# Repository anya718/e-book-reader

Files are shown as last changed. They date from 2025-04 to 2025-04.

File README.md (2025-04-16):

Biro Anya-Andreea 332CA

# OpenBook

## Diagrama bloc
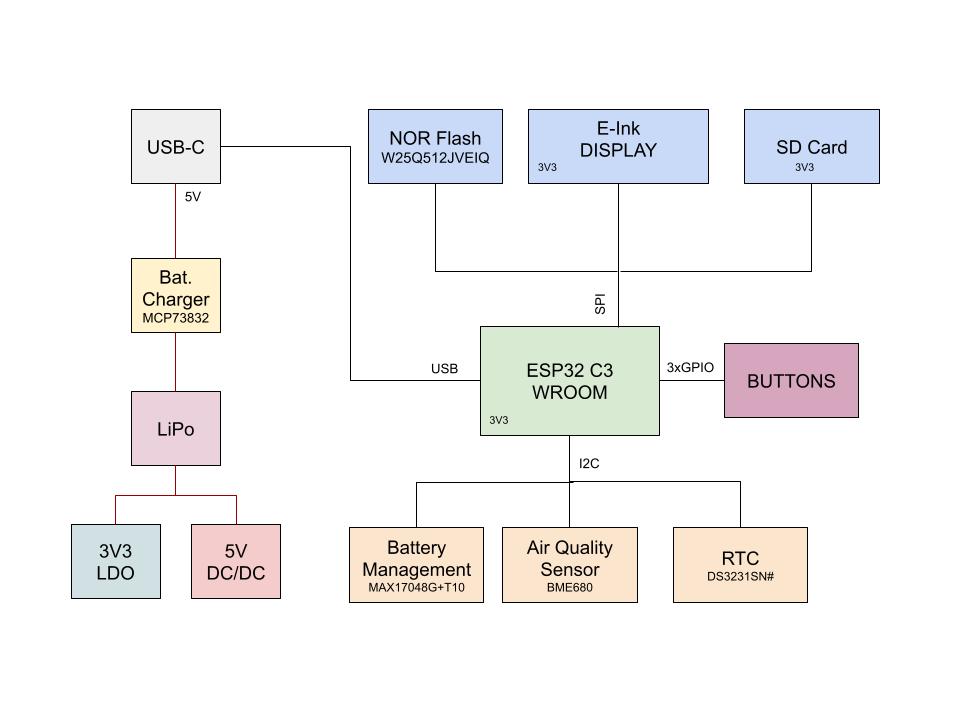
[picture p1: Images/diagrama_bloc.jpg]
Diagrama bloc


## BOM
| Componenta | Descriere | Sursa | Datasheet |
|---|---|---|---|
| ESP32-C6-WROOM-1-N8 | Multiprotocol Module ESP32 |[Mouser](https://ro.mouser.com/ProductDetail/Espressif-Systems/ESP32-C6-WROOM-1-N8?qs=8Wlm6%252BaMh8ST02Gmwp74cw%3D%3D)|[Datasheet](https://ro.mouser.com/datasheet/2/891/Espressif_ESP32_C6_WROOM_1__Datasheet_V0_1_PRELIMI-3239987.pdf)|
| USB4110-GF-A | USB Type C Connector |[Mouser](https://ro.mouser.com/ProductDetail/GCT/USB4110-GF-A?qs=KUoIvG%2F9IlYiZvIXQjyJeA%3D%3D)|[Datasheet](https://ro.mouser.com/datasheet/2/837/GCT_USB4110_Product_Drawing___20k_cycles-3455479.pdf)|
| 112A-TAAR-R03 | Micro SD Card Socket |[Comet](https://store.comet.srl.ro/Catalogue/Product/43497/)|[Datasheet](https://store.comet.bg/download-file.php?id=27596)|
| BME680 | Air Quality Sensor |[Mouser](https://ro.mouser.com/ProductDetail/Bosch-Sensortec/BME680?qs=v271MhAjFHjo0yA%2FC4OnDQ%3D%3D)|[Datasheet](https://ro.mouser.com/datasheet/2/783/BST_BME680_DS001-1509608.pdf)|
| DS3231SN# | Real Time Clock |[Mouser](https://ro.mouser.com/ProductDetail/700-DS3231SN%23)|[Datasheet](https://ro.mouser.com/datasheet/2/609/DS3231-3421123.pdf)|
| EVQ-P4MB3K | Tactile Switch |[Mouser](https://ro.mouser.com/ProductDetail/Panasonic/EVQ-P4MB3K?qs=0aNVN3t2tDvlcmyoDZjvlA%3D%3D)|[Datasheet](https://4donline.ihs.com/images/VipMasterIC/IC/PANA/PANA-S-A0000771493/PANA-S-A0000771493-1.pdf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)|
| MCP73831-2ACI/MC | Battery Charge Controller |[Mouser](https://ro.mouser.com/ProductDetail/579-MCP73831-2ACI-MC)|[Datasheet](https://ro.mouser.com/datasheet/2/268/MCP73831_Family_Data_Sheet_DS20001984H-3441711.pdf)|
| MAX17048G+T10 | Battery Management |[Mouser](https://ro.mouser.com/ProductDetail/Analog-Devices-Maxim-Integrated/MAX17048G%2bT10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)|[Datasheet](https://ro.mouser.com/datasheet/2/609/MAX17048_MAX17049-3469099.pdf)|
| FH34SRJ-24S-0.5SH(99) | EPD Connector |[Mouser](https://ro.mouser.com/ProductDetail/Hirose-Connector/FH34SRJ-24S-0.5SH99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)|[Datasheet](https://ro.mouser.com/datasheet/2/185/FH34SRJ_24S_0_5SH_99__CL0580_1255_6_99_2DDrawing_0-1615044.pdf)|
| PRT-14417 | Qwiic JST Connector |[Mouser](https://ro.mouser.com/ProductDetail/SparkFun/PRT-14417?qs=wd5RIQLrsJhgdz%2FpmZ%2F3GQ%3D%3D)|[Datasheet](https://ro.mouser.com/datasheet/2/813/Qwiic_Connector_Datasheet-1223982.pdf)|
| W25Q512JVEIQ | NOR Flash |[Mouser](https://ro.mouser.com/ProductDetail/Winbond/W25Q512JVEIQ?qs=l7cgNqFNU1jw6svr3at6tA%3D%3D)|[Datasheet](https://ro.mouser.com/datasheet/2/949/Winbond_W25Q512JV_Datasheet-3240039.pdf)|
| R0402 | Resistor |[Mouser](https://ro.mouser.com/ProductDetail/Panasonic/ERJ-2BWJR051X?qs=pojneS%2F1sjx%252Bdeocf%252BMSog%3D%3D)|[Datasheet](https://industrial.panasonic.com/cdbs/www-data/pdf/RDN0000/AOA0000C313.pdf)|
| B72540T0300K062 | Varistor |[Mouser](https://ro.mouser.com/ProductDetail/EPCOS-TDK/B72540T0300K062?qs=dEfas%2FXlABK4d0Dv0OnYYg%3D%3D)|[Datasheet](https://www.tdk-electronics.tdk.com/inf/75/db/CTVS_14/Surge_protection_series.pdf)|
| C0402C475K8PACTU | Capacitor |[Mouser](https://ro.mouser.com/ProductDetail/KEMET/C0402C475K8PACTU?qs=ulEaXIWI0c9ebKRT3r3htg%3D%3D)|[Datasheet](https://ro.mouser.com/datasheet/2/447/KEM_C1006_X5R_SMD-3316465.pdf)|
| T491B107M006AT | Tantalum Capacitor |[Mouser](https://ro.mouser.com/ProductDetail/KEMET/T491B107M006AT?qs=U312oeP%2FpiHOgyk6KO2m0g%3D%3D)|[Datasheet](https://ro.mouser.com/datasheet/2/447/KEM_T2005_T491-3316937.pdf)|
| USBLC6-2SC6Y | ESD Protection Diode |[Mouser](https://ro.mouser.com/ProductDetail/STMicroelectronics/USBLC6-2SC6Y?qs=gNDSiZmRJS%2FOgDexvXkdow%3D%3D)|[Datasheet](https://ro.mouser.com/datasheet/2/389/usblc6_2sc6y-1852505.pdf)|
| PGB1010603MR | ESD Protection Diode |[Mouser](https://ro.mouser.com/ProductDetail/Littelfuse/PGB1010603MR?qs=gu7KAQ731URLg4GSnNNN7Q%3D%3D)|[Datasheet](https://www.littelfuse.com/assetdocs/pulseguard-esd-suppressors-pgb1-datasheet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)|
| SD0805S020S1R0 | Schottky Diode |[Mouser](https://ro.mouser.com/ProductDetail/KYOCERA-AVX/SD0805S020S1R0?qs=jCA%252BPfw4LHbpkAoSnwrdjw%3D%3D)|[Datasheet](https://ro.mouser.com/datasheet/2/40/schottky-3165252.pdf)|
| MBR0530-TP | Small Signal Schottky Diode |[Mouser](https://ro.mouser.com/ProductDetail/Micro-Commercial-Components-MCC/MBR0530-TP?qs=KFo7JewZbUECRHkxGanrdg%3D%3D)|[Datasheet](https://ro.mouser.com/datasheet/2/258/MBR0520_MBR0580_SOD123_-2492194.pdf)|
| LSM0603472V | Single Color LED |[Mouser](https://ro.mouser.com/ProductDetail/VCC/LSM0603472V?qs=%252BEew9%252B0nqrBygsW37Z2ISQ%3D%3D)|[Datasheet](https://ro.mouser.com/datasheet/2/423/LSM0603472V_(1)-1379786.pdf)|
| DMG2305UX-7 | MOSFET P-Ch |[Mouser](https://ro.mouser.com/ProductDetail/Diodes-Incorporated/DMG2305UX-7?qs=L1DZKBg7t5F%2FNBHrjfxC%252Bg%3D%3D)|[Datasheet](https://www.diodes.com/assets/Datasheets/DMG2305UX.pdf)|
| SI1308EDL-T1-GE3 | MOSFET N-Ch |[Mouser](https://ro.mouser.com/ProductDetail/Vishay-Semiconductors/SI1308EDL-T1-GE3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)|[Datasheet](https://www.vishay.com/docs/63399/si1308edl.pdf)|
| CPH3225A | Supercapacitor |[Mouser](https://ro.mouser.com/ProductDetail/Seiko-Semiconductors/CPH3225A?qs=3etwrb1wR%252BhUOph6lAO7eg%3D%3D)|[Datasheet](https://ro.mouser.com/datasheet/2/360/Seiko_Instruments_MicroBattery_E_20230330_2024Jan_-3561061.pdf)|
| 744043680 | SMD Inductor |[Mouser](https://ro.mouser.com/ProductDetail/Wurth-Elektronik/744043680?qs=PGXP4M47uW6VkZq%252BkzjrHA%3D%3D)|[Datasheet](https://www.we-online.com/components/products/datasheet/744043680.pdf)|
| BD5229G-TR | Voltage Detector |[Mouser](https://ro.mouser.com/ProductDetail/ROHM-Semiconductor/BD5229G-TR?qs=4kLU8WoGk0vvnhrrYwdszw%3D%3D)|[Datasheet](https://fscdn.rohm.com/en/products/databook/datasheet/ic/power/voltage_detector/bd52xxg-e.pdf)|
| XC6220A331MR-G | LDO Voltage Regulator |[Mouser](https://ro.mouser.com/ProductDetail/Torex-Semiconductor/XC6220A331MR-G?qs=AsjdqWjXhJ8ZSWznL1J0gg%3D%3D)|[Datasheet](https://ro.mouser.com/datasheet/2/760/xc6220-3371556.pdf)|

## Descriere funcționalitate hardware
Proiectul **OpenBook** are ca scop dezvoltarea unui dispozitiv portabil de afișare a informațiilor, cu consum redus de energie, conectivitate Wi-Fi și senzori de mediu.

### Module și interfețe utilizate

- **ESP32-C6** – Microcontroller central cu suport pentru Wi-Fi și BLE. Rulează logica principală și gestionează comunicația cu toate perifericele.
- **BME680** – Senzor pentru calitatea aerului, conectat prin magistrala I2C.
- **DS3231SN** – Ceas de timp real (RTC), conectat I2C.
- **W25Q512JVEIQ** – Memorie NOR Flash SPI pentru stocare de date suplimentară.
- **MAX17048** – Circuit de monitorizare a bateriei, interfață I2C.
- **MCP73831** – Controler de încărcare baterie LiPo.
- **Conector EPD + ecran E-Ink** – Conectat SPI, pentru afișare cu consum redus.
- **Slot microSD** – SPI, pentru citire/scriere fișiere.
- **Buton tactile (EVQ-P4MB3K)** – Intrare digitală, GPIO.
- **Conector USB-C (USB4110-GF-A)** – Încărcare și interfață serială.
- **LED + rezistor + MOSFET** – Indicatoare vizuale, controlate de GPIO.
- **Diodă Schottky, varistori, ESD diode** – Protecție electrică.

### Comunicație și consum

- I2C: folosit pentru BME680, RTC, Battery Gauge
- SPI: utilizat pentru ecranul E-Ink, memoria Flash și SD card
- GPIO: pentru butoane, LED-uri, MOSFET-uri
- UART: pentru debugging via USB
- Estimare consum: 
    - **Mod Activ:** ~220 mA @ 3.3V → ~727 mW  
    - **Mod Sleep:** ~27 µA @ 3.3V → ~0.089 mW  
    - **Autonomie estimată:** ~14 zile cu baterie Li-Po 1200mAh

## Mapare Pini ESP32-C6

| Componentă | Pin ESP32-C6 | Interfață |
|---|---|---|
| BME680 | GPIO4 (SDA), GPIO5 (SCL) | I2C |
| DS3231SN | GPIO4, GPIO5 | I2C |
| E-Ink Display | GPIO10, GPIO11, ...  | SPI |
| SD Card | GPIO10, GPIO11, ...  | SPI |
| MAX17048 | GPIO4, GPIO5 | I2C |
| MCP73831 | GPIO22 (STAT) | GPIO |
| Buton | GPIO12 | GPIO |
| LED | GPIO13 | GPIO |
| UART (debug) | GPIO20 (TX), GPIO21 (RX) | UART |

## Alte Informații Relevante
- Fișiere schematice și PCB disponibile în `/Hardware`
- Fișiere 3D disponibile în `/Mechanical`
- Randări ale PCB-ului:
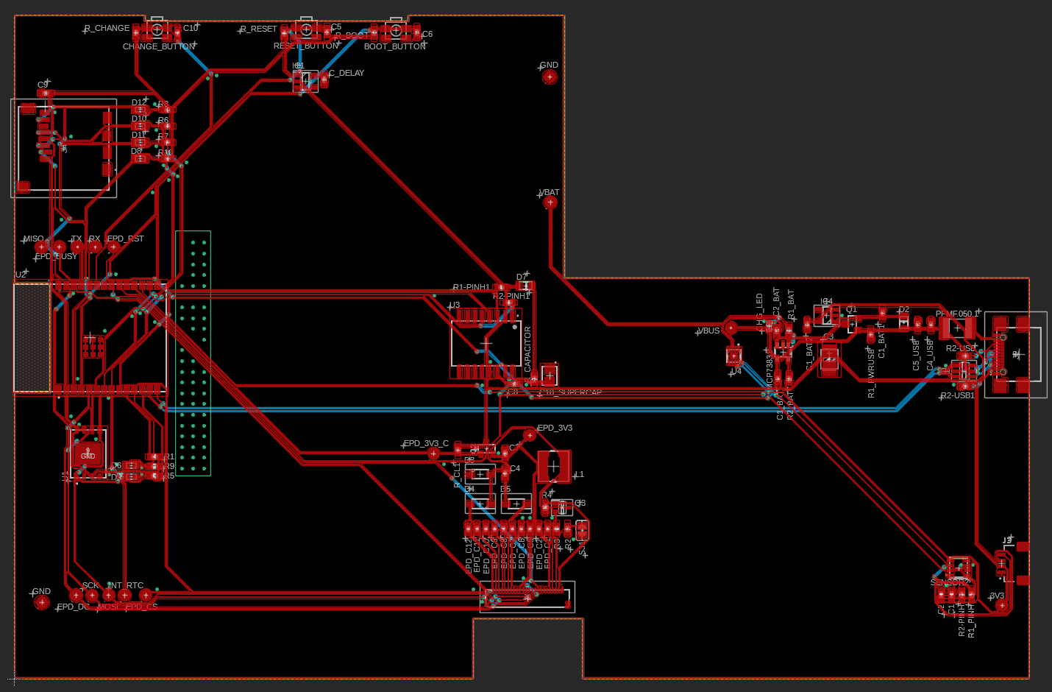
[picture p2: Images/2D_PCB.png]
PCB_2D

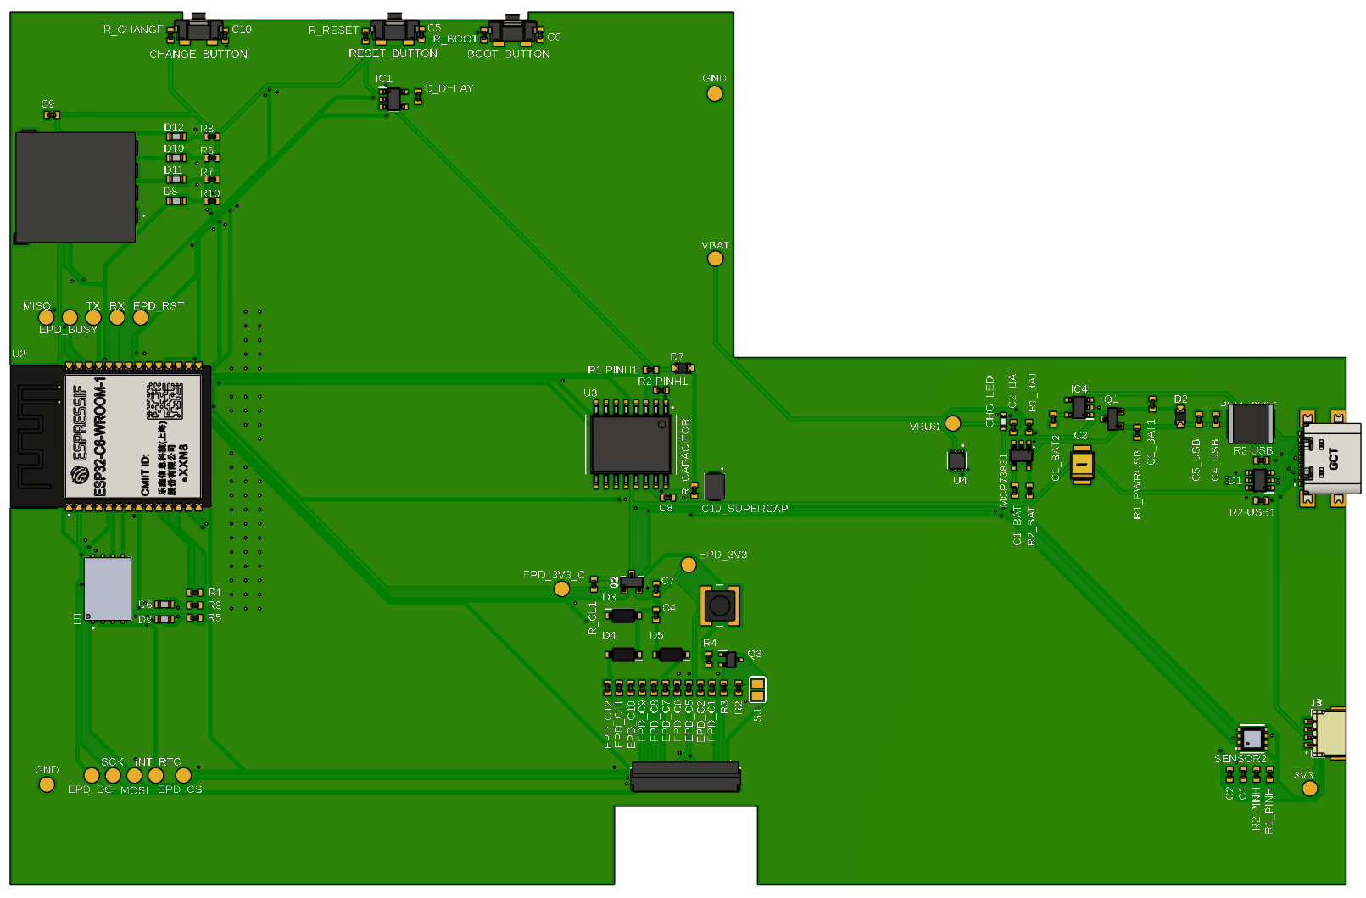
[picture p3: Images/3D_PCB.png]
PCB_3D

- Randări ale dispozitivului:
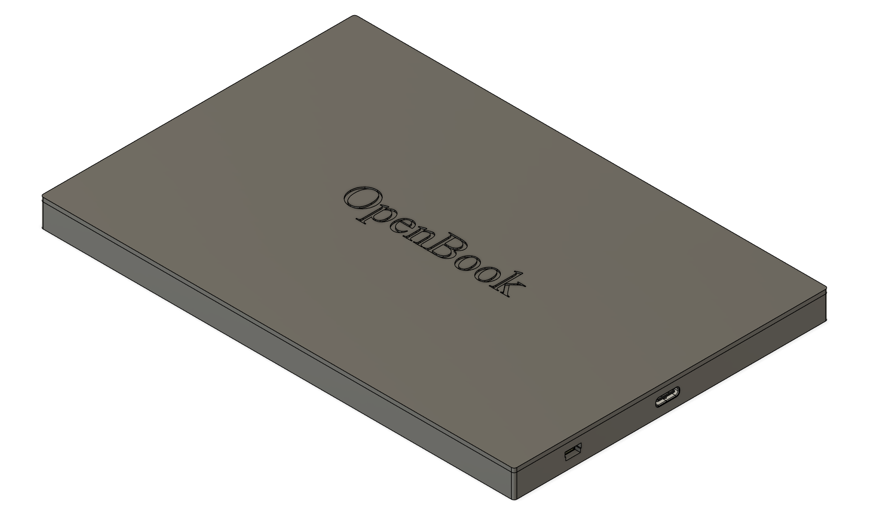
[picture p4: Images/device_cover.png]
Carcasă

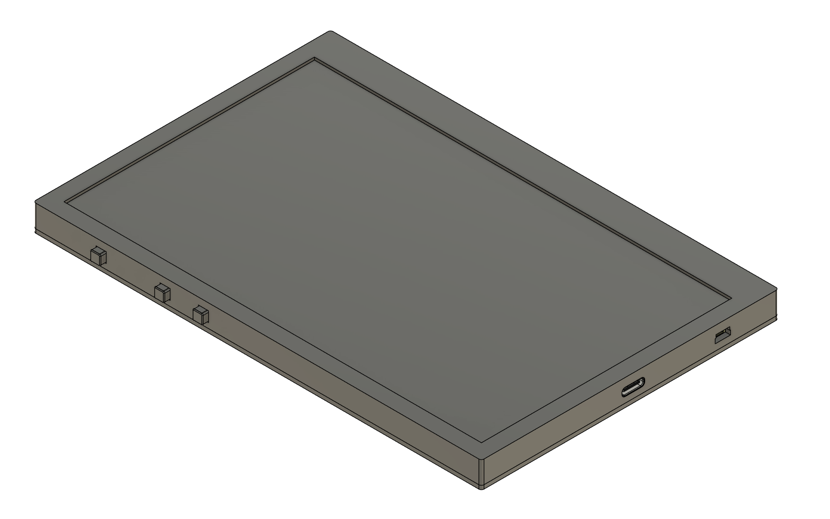
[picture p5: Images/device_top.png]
Ecran

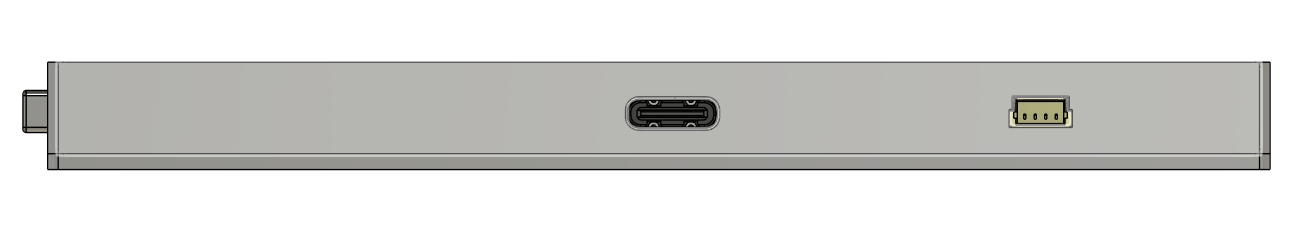
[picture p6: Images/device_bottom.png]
Mufe

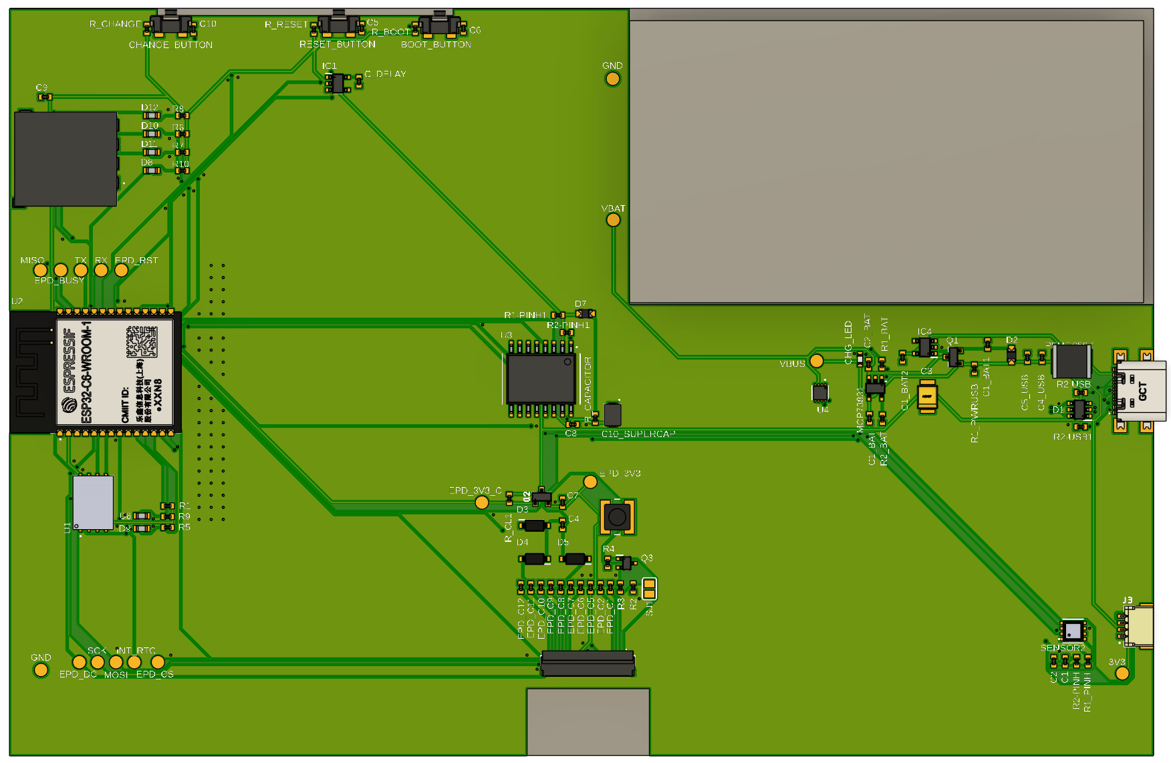
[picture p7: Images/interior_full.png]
Interior


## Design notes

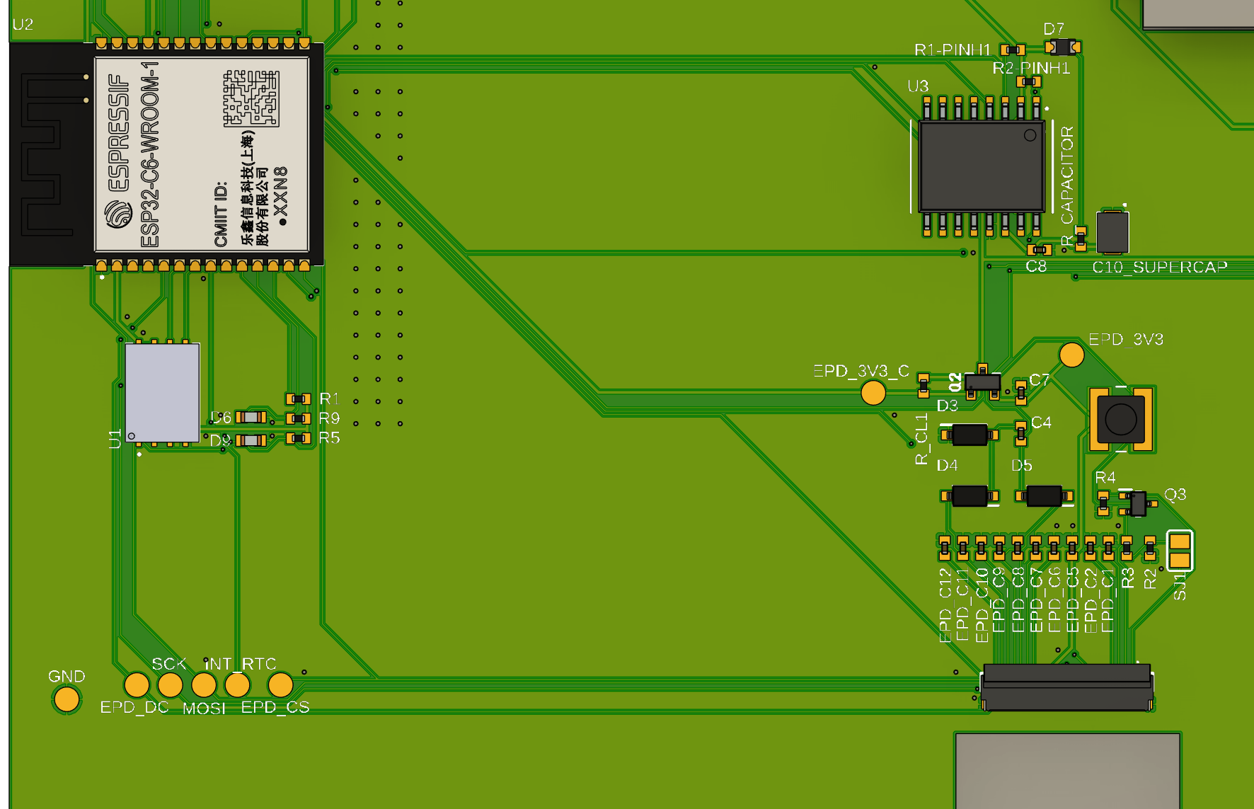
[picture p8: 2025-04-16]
Images/interior_section_1.png

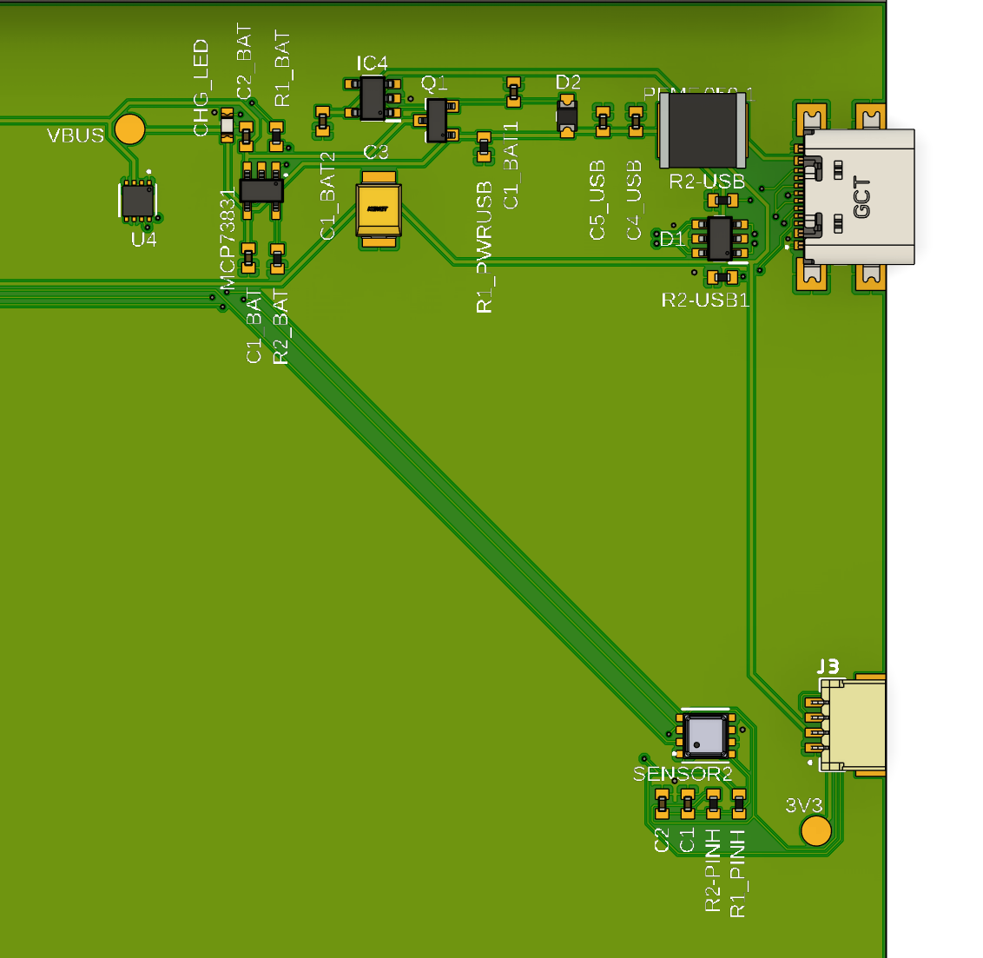
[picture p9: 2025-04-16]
Images/interior_section_2.png

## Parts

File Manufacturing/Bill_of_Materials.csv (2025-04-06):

Qty | Value | Device | Package | Parts | Description | ARROW_PART_NUMBER | ARROW_PRICE-STOCK | AVAILABILITY | BME688 | CENTROID_NOT_SPECIFIED | CHECK_PRICES | COPYRIGHT | CUSTOM_VAL | DATASHEET | DESCRIPTION | DIGIKEY_DESCRIPTION | DIGIKEY_PART_NUMBER | DMG2305UX-7 | HEIGHT | LEAD_FREE | MANUFACTURER_NAME | MANUFACTURER_PART_NUMBER | MF | MFR_NAME | MOUSER_PART_NUMBER | MOUSER_PRICE-STOCK | MOUSER_TESTING_PART_NUMBER | MOUSER_TESTING_PRICE-STOCK | MP | MPN | PACKAGE | POPULARITY | PREFIX | PRICE | PROD_ID | PURCHASE-URL | ROHS | SD0805S020S1R0 | SNAPEDA_LINK | SPICEMODEL | SPICEPREFIX | TEMPERATURE_RANGE_HIGH | TEMPERATURE_RANGE_LOW | TP_SIGNAL_NAME | VALUE
1 |  | ADAFRUIT_LEDCHIP-LED0603 | ADAFRUIT_CHIP-LED0603 | CHG_LED | LED
1 |  | SJ | SJ | SJ1 | SMD solder JUMPER |  |  |  |  |  |  |  |  |  |  |  |  |  |  |  |  |  |  |  |  |  |  |  |  |  |  | 3
1 | 0.1uF/50V | ESP32_WROVER_EAGLE-LTSPICE_CC0402 | ESP32_WROVER_EAGLE-LTSPICE_C0402 | EPD_C5 | CAPACITOR, European symbol |  |  |  |  |  |  |  |  |  |  |  |  |  |  |  |  |  |  |  |  |  |  |  |  |  |  |  |  |  |  |  |  |  |  | NONE | C
1 | 0.47 | ESP32_WROVER_EAGLE-LTSPICE_RR0402 | ESP32_WROVER_EAGLE-LTSPICE_R0402 | R3 | RESISTOR, European symbol |  |  |  |  |  |  |  |  |  |  |  |  |  |  |  |  |  |  |  |  |  |  |  |  |  |  |  |  |  |  |  |  |  |  | NONE | R
1 | 100k | ESP32_WROVER_EAGLE-LTSPICE_RR0402 | ESP32_WROVER_EAGLE-LTSPICE_R0402 | R1_PWRUSB | RESISTOR, European symbol |  |  |  |  |  |  |  |  |  |  |  |  |  |  |  |  |  |  |  |  |  |  |  |  |  |  |  |  |  |  |  |  |  |  | NONE | R
8 | 100nF | ESP32_WROVER_EAGLE-LTSPICE_CC0402 | ESP32_WROVER_EAGLE-LTSPICE_C0402 | C1, C2, C4_USB, C6, C8, C9, C10, C_DELAY | CAPACITOR, European symbol |  |  |  |  |  |  |  |  |  |  |  |  |  |  |  |  |  |  |  |  |  |  |  |  |  |  |  |  |  |  |  |  |  |  | NONE | C
1 | 100uF TANT | RCL_CPOL-EUCT3528 | RCL_CT3528 | C3 | POLARIZED CAPACITOR, European symbol |  |  |  |  |  |  |  |  |  |  |  |  |  |  |  |  |  |  |  |  |  |  |  |  |  |  | 0 |  |  |  |  |  |  |  |  | C
16 | 10k | ESP32_WROVER_EAGLE-LTSPICE_RR0402 | ESP32_WROVER_EAGLE-LTSPICE_R0402 | R1, R1-PINH1, R1_PINH, R2-PINH, R2-PINH1, R4, R5, R6, R7, R8, R9, R10, R_BOOT, R_CHANGE, R_CL1, R_RESET | RESISTOR, European symbol |  |  |  |  |  |  |  |  |  |  |  |  |  |  |  |  |  |  |  |  |  |  |  |  |  |  |  |  |  |  |  |  |  |  | NONE | R
1 | 10uF | ESP32_WROVER_EAGLE-LTSPICE_CC0402 | ESP32_WROVER_EAGLE-LTSPICE_C0402 | C7 | CAPACITOR, European symbol |  |  |  |  |  |  |  |  |  |  |  |  |  |  |  |  |  |  |  |  |  |  |  |  |  |  |  |  |  |  |  |  |  |  | NONE | C
1 | 112A-TAAR-R03_ATTEND | 112A-TAAR-R03_ATTEND | 112ATAARR03ATTEND | J4 | Micro SD Card Socket, Push-Push Type, Top Mount, SMT, H=1.83mm, 10u |  |  |  |  |  |  |  |  |  | Micro SD Card Socket | Push-Push Type | Top Mount | SMT | H=1.83mm | 10u |  |  |  | 1.9mm |  | ATTEND | 112A-TAAR-R03 ATTEND
1 | 15 | ESP32_WROVER_EAGLE-LTSPICE_RR0402 | ESP32_WROVER_EAGLE-LTSPICE_R0402 | R_CAPACITOR | RESISTOR, European symbol |  |  |  |  |  |  |  |  |  |  |  |  |  |  |  |  |  |  |  |  |  |  |  |  |  |  |  |  |  |  |  |  |  |  | NONE | R
1 | 1uF | ESP32_WROVER_EAGLE-LTSPICE_CC0402 | ESP32_WROVER_EAGLE-LTSPICE_C0402 | C5 | CAPACITOR, European symbol |  |  |  |  |  |  |  |  |  |  |  |  |  |  |  |  |  |  |  |  |  |  |  |  |  |  |  |  |  |  |  |  |  |  | NONE | C
9 | 1uF/50V | ESP32_WROVER_EAGLE-LTSPICE_CC0402 | ESP32_WROVER_EAGLE-LTSPICE_C0402 | EPD_C1, EPD_C2, EPD_C6, EPD_C7, EPD_C8, EPD_C9, EPD_C10, EPD_C11, EPD_C12 | CAPACITOR, European symbol |  |  |  |  |  |  |  |  |  |  |  |  |  |  |  |  |  |  |  |  |  |  |  |  |  |  |  |  |  |  |  |  |  |  | NONE | C
1 | 2.2 | ESP32_WROVER_EAGLE-LTSPICE_RR0402 | ESP32_WROVER_EAGLE-LTSPICE_R0402 | R2 | RESISTOR, European symbol |  |  |  |  |  |  |  |  |  |  |  |  |  |  |  |  |  |  |  |  |  |  |  |  |  |  |  |  |  |  |  |  |  |  | NONE | R
1 | 200 | ESP32_WROVER_EAGLE-LTSPICE_RR0402 | ESP32_WROVER_EAGLE-LTSPICE_R0402 | R1_BAT | RESISTOR, European symbol |  |  |  |  |  |  |  |  |  |  |  |  |  |  |  |  |  |  |  |  |  |  |  |  |  |  |  |  |  |  |  |  |  |  | NONE | R
2 | 20V/4.2A/52mO/1.4W | ESP32_WROVER_SPARKFUN-DISCRETESEMI_MOSFET_PCH-DMG2305UX-7 | ESP32_WROVER_SPARKFUN-DISCRETESEMI_SOT23-3 | Q1, Q2 | P-channel MOSFETs |  |  |  |  |  |  |  |  |  |  |  |  |  |  |  |  |  |  |  |  |  |  |  |  |  |  |  |  |  | TRAN-14388 |  |  |  |  |  |  |  |  |  | 20V/4.2A/52mO/1.4W
1 | 2k | ESP32_WROVER_EAGLE-LTSPICE_RR0402 | ESP32_WROVER_EAGLE-LTSPICE_R0402 | R2_BAT | RESISTOR, European symbol |  |  |  |  |  |  |  |  |  |  |  |  |  |  |  |  |  |  |  |  |  |  |  |  |  |  |  |  |  |  |  |  |  |  | NONE | R
5 | 4.7uF | ESP32_WROVER_EAGLE-LTSPICE_CC0402 | ESP32_WROVER_EAGLE-LTSPICE_C0402 | C1_BAT, C1_BAT1, C1_BAT2, C2_BAT, C5_USB | CAPACITOR, European symbol |  |  |  |  |  |  |  |  |  |  |  |  |  |  |  |  |  |  |  |  |  |  |  |  |  |  |  |  |  |  |  |  |  |  | NONE | C
1 | 4.7uF/25V | ESP32_WROVER_EAGLE-LTSPICE_CC0402 | ESP32_WROVER_EAGLE-LTSPICE_C0402 | C4 | CAPACITOR, European symbol |  |  |  |  |  |  |  |  |  |  |  |  |  |  |  |  |  |  |  |  |  |  |  |  |  |  |  |  |  |  |  |  |  |  | NONE | C
2 | 5k1 | ESP32_WROVER_EAGLE-LTSPICE_RR0402 | ESP32_WROVER_EAGLE-LTSPICE_R0402 | R2-USB, R2-USB1 | RESISTOR, European symbol |  |  |  |  |  |  |  |  |  |  |  |  |  |  |  |  |  |  |  |  |  |  |  |  |  |  |  |  |  |  |  |  |  |  | NONE | R
1 | 68uH | 744043680IND_4828-WE-TPC_WRE | IND_4828-WE-TPC_WRE | L1 |  |  |  |  |  |  |  | Copyright (C) 2024 Ultra Librarian. All rights reserved. | 68uH |  |  |  |  |  |  |  |  | 744043680 |  | Wurth Electronics
1 | BD5229G-TR | BD5229G-TR | SOT95P280X125-5N | IC1 | Voltage Detector with Adjustable Delay Time: CMOS processes are utilized to develop high precision, low current consumption CMOS reset ICs that allow arbitrary setting of the delay time. The extensive lineup includes both Nch Open Drain and CMOS output types in a wide range of detection voltages (from 2.3V to 6.0V, in 0.1V steps), enabling selection of the ideal solution based on customer requirements. In addition, the entire series is of course both lead-free and RoHS-compliant. |  |  |  |  |  |  |  |  |  | Voltage Detector with Adjustable Delay Time: CMOS processes are utilized to develop high precision | low current consumption CMOS reset ICs that allow arbitrary setting of the delay time. The extensive lineup includes both Nch Open Drain and CMOS output types in a wide range of detection voltages (from 2.3V to 6.0V | in 0.1V steps) | enabling selection of the ideal solution based on customer requirements. In addition | the entire series is of course both lead-free and RoHS-compliant. |  |  |  | 1.25mm |  | ROHM Semiconductor | BD5229G-TR |  |  | 755-BD5229G-TR | https://www.mouser.co.uk/ProductDetail/ROHM-Semiconductor/BD5229G-TR?qs=4kLU8WoGk0vvnhrrYwdszw%3D%3D
3 | BUTTON_CUSYOMV1 | BUTTON_CUSYOMV1 | MYBUTTON | BOOT_BUTTON, CHANGE_BUTTON, RESET_BUTTON
1 | CPH3225A | CPH3225A | CAPCP3225X100N | C10_SUPERCAP | Cap 0.011F 3.3V 1210 Flat Check availability |  |  | Not in stock |  |  | https://www.snapeda.com/parts/CPH3225A/Seiko+Instruments/view-part/?ref=eda |  |  |  | 11 mF (EDLC) Supercapacitor 3.3 V 1210 (3225 Metric) - - |  |  |  |  |  |  |  | Seiko Instruments |  |  |  |  |  | CPH3225A |  | 1210 Seiko |  |  | None |  | https://www.snapeda.com/api/url_track_click_mouser/?unipart_id=562593&manufacturer=Seiko Instruments&part_name=CPH3225A&search_term=None |  |  | https://www.snapeda.com/parts/CPH3225A/Seiko+Instruments/view-part/?ref=snap
1 | DS3231SN# | DS3231SN# | SOIC127P1032X265-16N | U3 | Real Time Clock Serial 16-Pin SOIC W T/R Check availability |  |  | In Stock |  |  | https://www.snapeda.com/parts/DS3231SN%23/Analog+Devices/view-part/?ref=eda |  |  |  | Extremely Accurate I²C-Integrated RTC/TCXO/Crystal |  |  |  |  |  |  |  | Analog Devices |  |  |  |  |  | DS3231SN# |  | SOIC-16 Maxim |  |  | None |  | https://www.snapeda.com/api/url_track_click_mouser/?unipart_id=99048&manufacturer=Analog Devices&part_name=DS3231SN#&search_term=None |  |  | https://www.snapeda.com/parts/DS3231SN%23/Analog+Devices/view-part/?ref=snap
1 | ESP32-C6-WROOM-1-N8 | ESP32-C6-WROOM-1-N8 | XCVR_ESP32-C6-WROOM-1-N8 | U2 | Check availability |  |  | In Stock |  |  | https://www.snapeda.com/parts/ESP32-C6-WROOM-1-N8/Espressif+Systems/view-part/?ref=eda |  |  |  | Multiprotocol Modules ESP32-C6 module | Wi-Fi 6 in 2.4 GHz band | Bluetooth 5 | Zigbee 3.0 and Thread. ESP34-WROOM Compatible - ENGINEERING SAMPLE |  |  |  |  |  |  |  | Espressif Systems |  |  |  |  |  | ESP32-C6-WROOM-1-N8 |  | None |  |  | None |  |  |  |  | https://www.snapeda.com/parts/ESP32-C6-WROOM-1-N8/Espressif+Systems/view-part/?ref=snap
1 | ESP32C6_VARISTORCN1812 | ESP32C6_VARISTORCN1812 | ESP32C6_VARISTOR_CT/CN1812 | PFMF.050.1 | VARISTOR |  |  |  |  |  |  |  |  |  |  |  |  |  |  |  |  |  |  |  |  |  |  |  |  |  |  | 0
2 | ESP32_WROVER_AVX---SD0805S020S1R0_AVX_SD0805S020S1R0_0_0AVX_SD0805S020S1R0_0_0 | ESP32_WROVER_AVX---SD0805S020S1R0_AVX_SD0805S020S1R0_0_0AVX_SD0805S020S1R0_0_0 | ESP32_WROVER_AVX---SD0805S020S1R0_AVX_SD0805S020S1R0_0 | D2, D7 | Schottky Barrier Rectifier Diode |  |  |  |  | No |  |  |  | http://datasheets.avx.com/schottky.pdf |  | DIODE SCHOTTKY 20V 1A 0805 | 478-7800-1-ND |  |  | yes |  |  | AVX |  | 581-SD0805S020S1R0 |  |  |  |  |  | 0805 (2012 metric) |  | D |  |  |  | yes |  |  |  |  | +125°C | -55°C
1 | ESP32_WROVER_BME680_BME680 | ESP32_WROVER_BME680_BME680 | ESP32_WROVER_BME680_PSON80P300X300X100-8N | SENSOR2 | Integrated Environmental Unit |  |  | Unavailable |  |  |  |  |  |  | Integrated Environmental Unit |  |  |  |  |  |  |  | Bosch Sensortec |  |  |  |  |  | BME680 |  | LGA-8 Bosch Tools |  |  | None
1 | ESP32_WROVER_SPARKFUN-IC-POWER_MCP73831 | ESP32_WROVER_SPARKFUN-IC-POWER_MCP73831 | ESP32_WROVER_SPARKFUN-IC-POWER_SOT23-5 | MCP73831 | MCP73831T Li-Ion, Li-Pol Controller |  |  |  |  |  |  |  |  |  |  |  |  |  |  |  |  |  |  |  |  |  |  |  |  |  |  |  |  |  | IC-09995
1 | FH34SRJ-24S-0.5SH_99_ | FH34SRJ-24S-0.5SH_99_ | FH34SRJ24S05SH99 | J1 | (0.50mm) Surface Mount, Right Angle |  |  |  |  |  |  |  |  |  | 24 Position FFC | FPC Connector Contacts | (0.50mm) Surface Mount | Right Angle |  |  |  | 1.1mm |  | Hirose | FH34SRJ-24S-0.5SH(99) |  |  | 798-FH34SRJ24S05SH99 | https://www.mouser.co.uk/ProductDetail/Hirose-Connector/FH34SRJ-24S-0.5SH99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
1 | MAX17048G+T10 | MAX17048G+T10 | SON50P200X200X80-9N | U4 | Check availability |  |  | In Stock |  |  | https://www.snapeda.com/parts/MAX17048G+T10/Analog+Devices/view-part/?ref=eda |  |  |  | 3µA 1-Cell/2-Cell Fuel Gauge with ModelGauge |  |  |  |  |  |  |  | Analog Devices |  |  |  |  |  | MAX17048G+T10 |  | TDFN-8 Maxim |  |  | None |  | https://www.snapeda.com/api/url_track_click_mouser/?unipart_id=329239&manufacturer=Analog Devices&part_name=MAX17048G+T10&search_term=None |  |  | https://www.snapeda.com/parts/MAX17048G+T10/Analog+Devices/view-part/?ref=snap
3 | MBR0530 | MBR0530 | SOD3716X135N | D3, D4, D5 | ON SEMICONDUCTOR - MBR0530 - DIODE, SCHOTTKY, 0.5A, 30V, SOD-123 |  |  | In Stock |  |  | https://www.snapeda.com/parts/MBR0530/Onsemi/view-part/?ref=eda |  |  |  | Diode Schottky 30 V 500mA Surface Mount SOD-123 |  |  |  |  |  |  |  | ON Semiconductor |  |  |  |  |  | MBR0530 |  | SOD-123-2 ON Semiconductor |  |  | None |  | https://www.snapeda.com/api/url_track_click_mouser/?unipart_id=179458&manufacturer=ON Semiconductor&part_name=MBR0530&search_term=None |  |  | https://www.snapeda.com/parts/MBR0530/Onsemi/view-part/?ref=snap
6 | PGB1010603MR | PGB1010603MR | DIOC1608X36N | D6, D8, D9, D10, D11, D12 | Check availability |  |  | In Stock |  |  | https://www.snapeda.com/parts/PGB1010603MR/Littelfuse/view-part/?ref=eda |  |  |  | 150V (Typ) Clamp - Ipp Tvs Diode Surface Mount 0603 (1608 Metric) |  |  |  |  |  |  |  | Littelfuse Inc. |  |  |  |  |  | PGB1010603MR |  | 0603 Littelfuse Inc. |  |  | None |  | https://www.snapeda.com/api/url_track_click_mouser/?unipart_id=5659453&manufacturer=Littelfuse Inc.&part_name=PGB1010603MR&search_term=None |  |  | https://www.snapeda.com/parts/PGB1010603MR/Littelfuse/view-part/?ref=snap
1 | QWIIC_RIGHT_ANGLE | QWIIC_CONNECTORJS-1MM | JST04_1MM_RA | J3 | SparkFun I2C Standard Qwiic Connector |  |  |  |  |  |  |  |  |  |  |  |  |  |  |  |  |  |  |  |  |  |  |  |  |  |  |  |  |  | CONN-13694 |  |  |  |  |  |  |  |  |  | QWIIC_RIGHT_ANGLE
1 | SAMACSYS_PARTS_USB4110-GF-A | SAMACSYS_PARTS_USB4110-GF-A | SAMACSYS_PARTS_USB4110GFA | J2 | CONN USB 2.0 TYPE-C R/A SMT |  |  |  |  |  |  |  |  |  | CONN USB 2.0 TYPE-C R/A SMT |  |  |  | 3.26mm |  | GCT (GLOBAL CONNECTOR TECHNOLOGY) | USB4110-GF-A |  |  | 640-USB4110-GF-A | https://www.mouser.co.uk/ProductDetail/GCT/USB4110-GF-A?qs=KUoIvG%2F9IlYiZvIXQjyJeA%3D%3D
1 | SI1308EDL-T1-GE3 | SI1308EDL-T1-GE3 | SOT65P210X110-3N | Q3 | MOSFET N-Ch 30V 1.5A TrenchFET SC70 Vishay Si1308EDL-T1-GE3 N-channel MOSFET Transistor, 1.5 A, 30 V, 3-Pin SC-70 |  |  | In Stock |  |  | https://www.snapeda.com/parts/SI1308EDL-T1-GE3/Vishay+Siliconix/view-part/?ref=eda |  |  |  | Si1308EDL-T1-GE3 N-channel MOSFET Transistor | 1.5 A | 30 V | 3-Pin SC-70 | Siliconix / Vishay SI1308EDL-T1-GE3 |  |  |  |  |  |  |  | Vishay Siliconix |  |  |  |  |  | SI1308EDL-T1-GE3 |  | SOT-323 Vishay Semiconductor |  |  | None |  | https://www.snapeda.com/api/url_track_click_mouser/?unipart_id=274603&manufacturer=Vishay Siliconix&part_name=SI1308EDL-T1-GE3&search_term=None |  |  | https://www.snapeda.com/parts/SI1308EDL-T1-GE3/Vishay+Siliconix/view-part/?ref=snap
17 | TPTP20R | TPTP20R | TP20R | TP1, TP2, TP3, TP4, TP5, TP6, TP7, TP8, TP9, TP10, TP11, TP12, TP13, TP14, TP15, TP16, TP17 | Test pad |  |  |  |  |  |  |  |  |  |  |  |  |  |  |  |  |  |  |  |  |  |  |  |  |  |  | 2
1 | USBLC6-2SC6Y | USBLC6-2SC6Y | SOT95P280X145-6N | D1 | Low Cap. ESD Protection Auto SOT-23-6 STMicroelectronics USBLC6-2SC6Y, Dual Uni-Directional TVS Diode Array, 6-Pin SOT-23 |  |  | In Stock |  |  | https://www.snapeda.com/parts/USBLC6-2SC6Y/STMicroelectronics/view-part/?ref=eda |  |  |  | 17V Clamp 5A (8/20µs) Ipp Tvs Diode Surface Mount SOT-23-6 |  |  |  |  |  |  |  | STMicroelectronics |  |  |  |  |  | USBLC6-2SC6Y |  | SOT-23-6 STMicroelectronics |  |  | None |  |  |  |  | https://www.snapeda.com/parts/USBLC6-2SC6Y/STMicroelectronics/view-part/?ref=snap
1 | W25Q512JVEIQ | W25Q512JVEIQ | SON127P600X800X80-9N | U1 | Check availability |  |  | In Stock |  |  | https://www.snapeda.com/parts/W25Q512JVEIQ/Winbond+Electronics/view-part/?ref=eda |  |  |  | FLASH - NOR Memory IC 512Mb (64M x 8) SPI - Quad I/O 133 MHz 8-WSON (8x6) |  |  |  |  |  |  |  | Winbond Electronics |  |  |  |  |  | W25Q512JVEIQ |  | Package |  |  | None |  |  |  |  | https://www.snapeda.com/parts/W25Q512JVEIQ/Winbond+Electronics/view-part/?ref=snap
1 | XC6220A331MR-G | XC6220A331MR-G | SOT95P280X120-5N | IC4 | LDO Voltage Regulators |  |  |  |  |  |  |  |  |  | LDO Voltage Regulators |  |  |  | 1.2mm |  | Torex | XC6220A331MR-G |  |  | 865-XC6220A331MR-G | https://www.mouser.co.uk/ProductDetail/Torex-Semiconductor/XC6220A331MR-G?qs=AsjdqWjXhJ8ZSWznL1J0gg%3D%3D

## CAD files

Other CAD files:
Mechanical/OpenBook_3D_Model.f3z

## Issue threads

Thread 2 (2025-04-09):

Poti adauga informatii in README.md

Adrian256256, 2025-04-09:
README trebuie să conțină minim:
O diagramă bloc cu toate componentele proiectului vostru și cum sunt ele legate (model [aici](https://docs.google.com/drawings/d/1UpxRyJNfczJHhNRvWdeb5kh_7IEUy5173odk93W_GSA/edit?usp=sharing)).
Un BOM (Bill Of Materials) sub formă de tabel cu componentele sau modulele pe care le-ați folosit și link-uri către locul de unde le puteți procura (folosiți [Mouser](http://www.mouser.com/) și [Comet](http://www.comet.srl.ro/)) și link către datasheet-ul lor.
Descrierea în detaliu a funcționalității hardware (ce module, componente, senzori, etc. ați folosit, prin ce interfețe se leagă la microcontroller-ul vostru, specificații de comunicație, procesare, calcule de consum de energie și orice altceva considerați relevant).
Descrieți în detaliu ce pini ai ESP32-C6 sunt folosiți pentru fiecare componentă și de ce.
Orice altceva considerați că ar fi relevant pentru review (design log, imagini cu randări ale PCB-ului, așezarea componentelor în carcasă etc.).

anya718, 2025-04-16:
Done.

Closed 2025-04-16.

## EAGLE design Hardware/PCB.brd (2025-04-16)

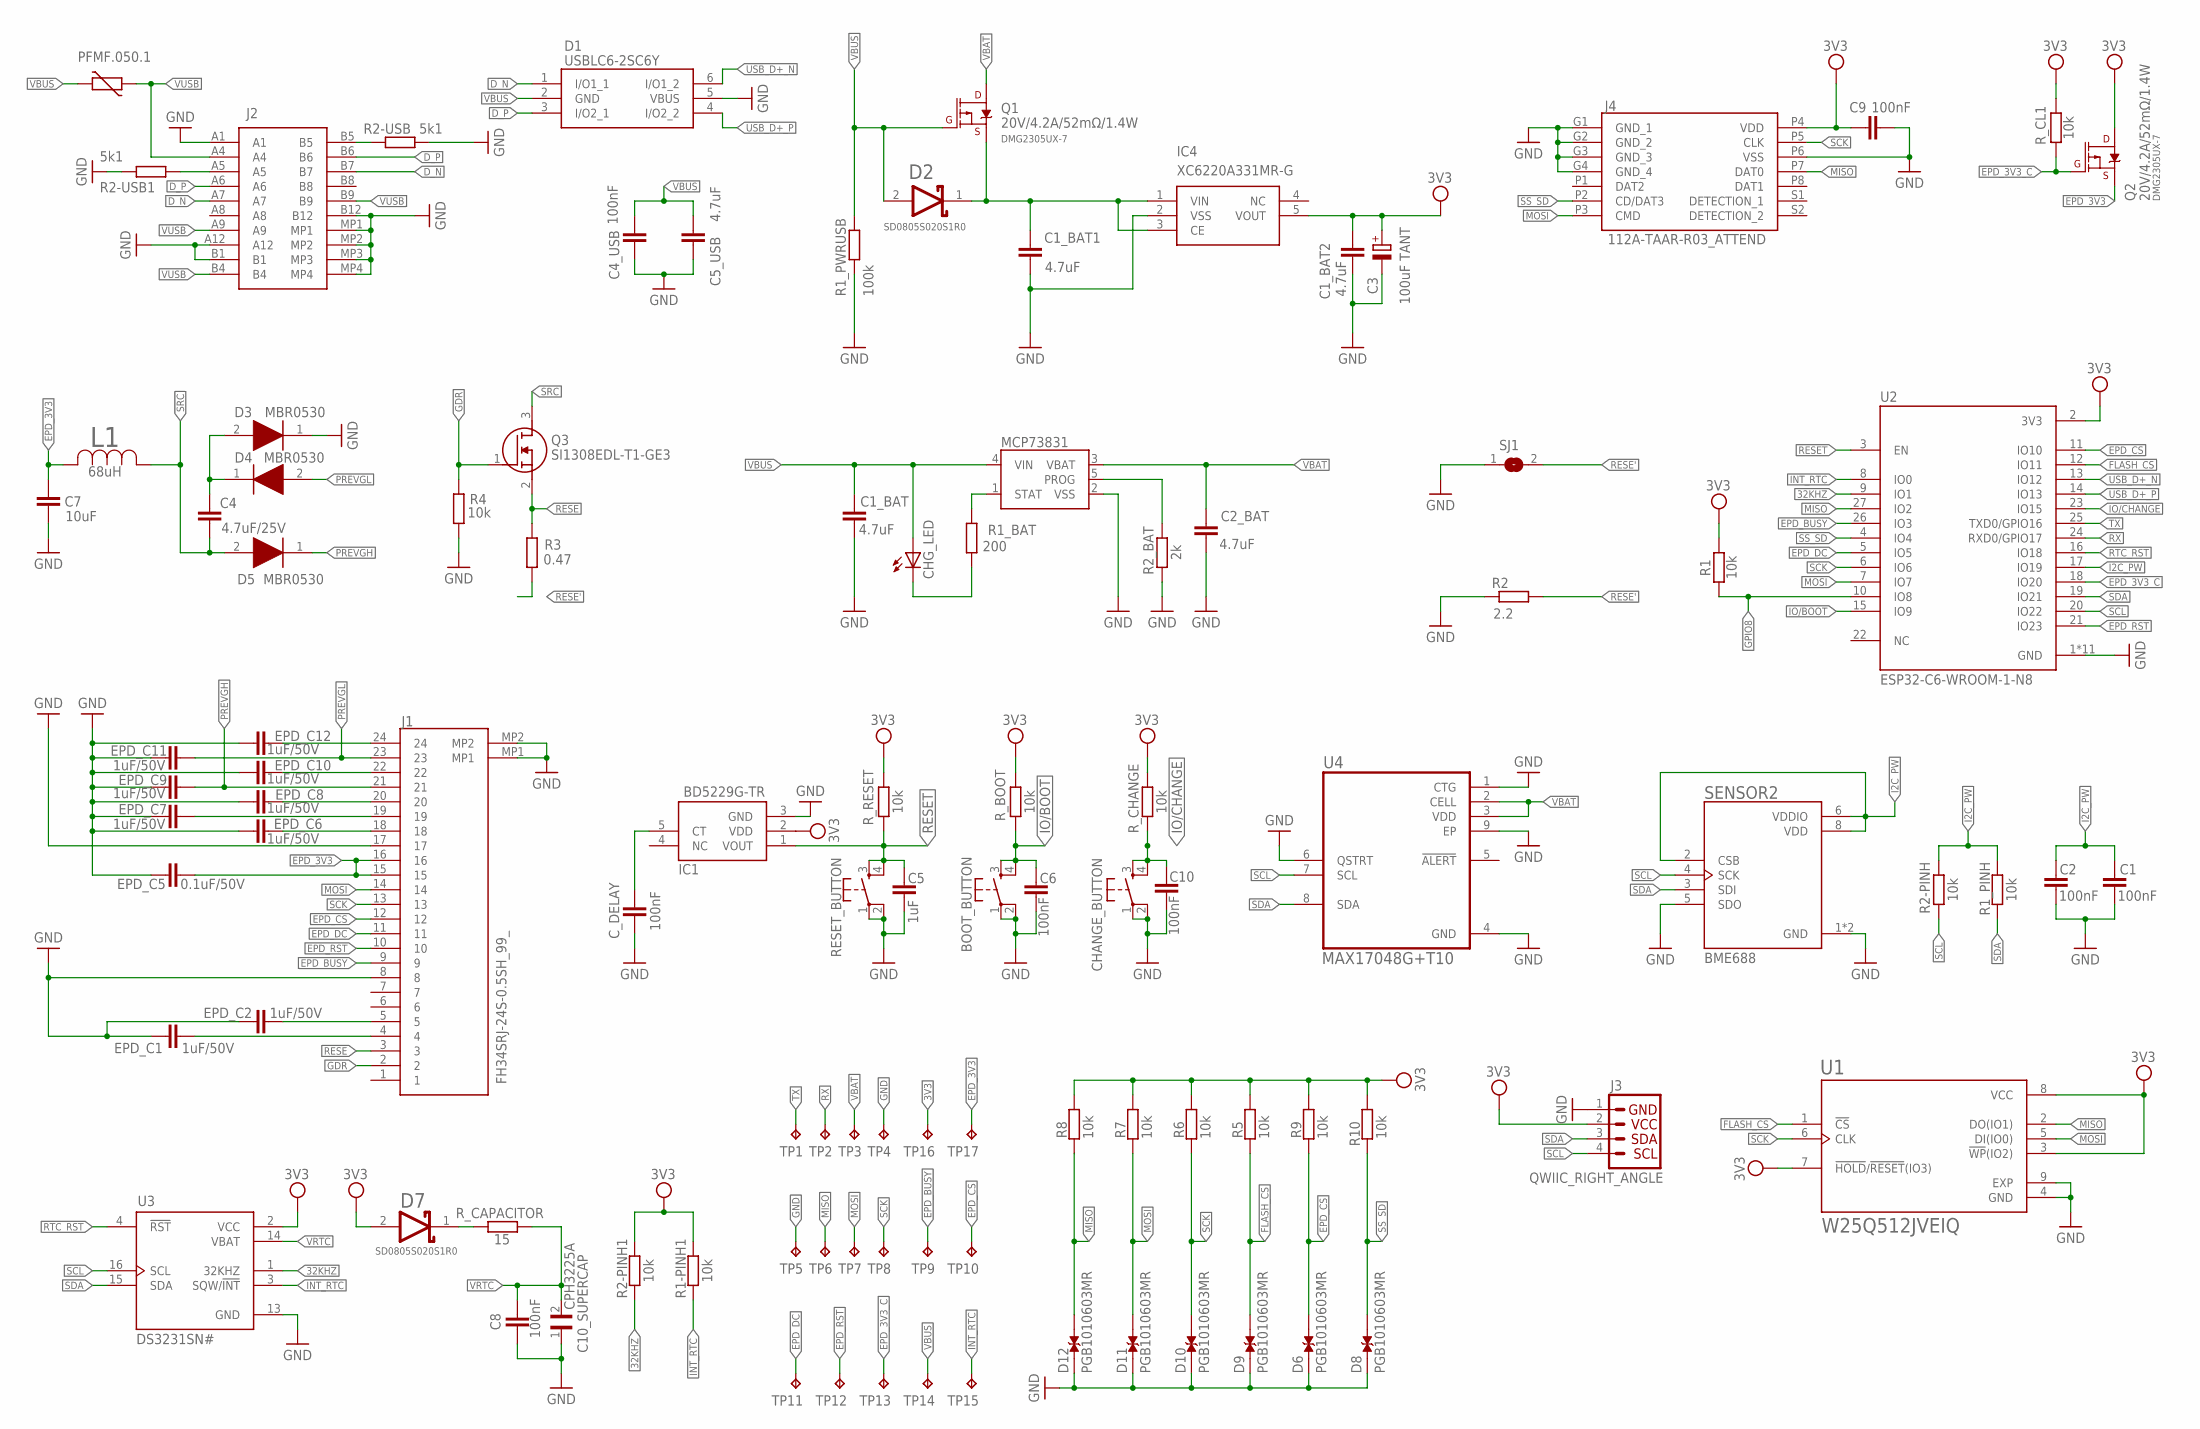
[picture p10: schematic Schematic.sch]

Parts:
BOOT_BUTTON: BUTTON_CUSYOMV1; MYBUTTON
C1, C2, C4_USB, C6, C8, C9, C10: 100nF; ESP32_WROVER_EAGLE-LTSPICE_C0402
C1_BAT, C1_BAT1, C1_BAT2, C2_BAT, C5_USB: 4.7uF; ESP32_WROVER_EAGLE-LTSPICE_C0402
C3: 100uF TANT; RCL_CT3528
C4: 4.7uF/25V; ESP32_WROVER_EAGLE-LTSPICE_C0402
C5: 1uF; ESP32_WROVER_EAGLE-LTSPICE_C0402
C7: 10uF; ESP32_WROVER_EAGLE-LTSPICE_C0402
C10_SUPERCAP: CPH3225A; CAPCP3225X100N
CHANGE_BUTTON: BUTTON_CUSYOMV1; MYBUTTON
CHG_LED: ADAFRUIT_LEDCHIP-LED0603; ADAFRUIT_CHIP-LED0603
C_DELAY: 100nF; ESP32_WROVER_EAGLE-LTSPICE_C0402
D1: USBLC6-2SC6Y; SOT95P280X145-6N
D2, D7: ESP32_WROVER_AVX---SD0805S020S1R0_AVX_SD0805S020S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; ESP32_WROVER_AVX---SD0805S020S1R0_AVX_SD0805S020S1R0_0
D3, D4, D5: MBR0530; SOD3716X135N
D6, D8, D9, D10, D11, D12: PGB1010603MR; DIOC1608X36N
EPD_C1, EPD_C2, EPD_C6, EPD_C7, EPD_C8, EPD_C9, EPD_C10, EPD_C11, EPD_C12: 1uF/50V; ESP32_WROVER_EAGLE-LTSPICE_C0402
EPD_C5: 0.1uF/50V; ESP32_WROVER_EAGLE-LTSPICE_C0402
IC1: BD5229G-TR; SOT95P280X125-5N
IC4: XC6220A331MR-G; SOT95P280X120-5N
J1: FH34SRJ-24S-0.5SH_99_; FH34SRJ24S05SH99
J2: SAMACSYS_PARTS_USB4110-GF-A; SAMACSYS_PARTS_USB4110GFA
J3: QWIIC_RIGHT_ANGLE; JST04_1MM_RA
J4: 112A-TAAR-R03_ATTEND; 112ATAARR03ATTEND
L1: 68uH; IND_4828-WE-TPC_WRE
MCP73831: ESP32_WROVER_SPARKFUN-IC-POWER_MCP73831; ESP32_WROVER_SPARKFUN-IC-POWER_SOT23-5
PFMF.050.1: ESP32C6_VARISTORCN1812; ESP32C6_VARISTOR_CT/CN1812
Q1, Q2: 20V/4.2A/52mΩ/1.4W; ESP32_WROVER_SPARKFUN-DISCRETESEMI_SOT23-3
Q3: SI1308EDL-T1-GE3; SOT65P210X110-3N
R1, R1-PINH1, R1_PINH, R2-PINH, R2-PINH1, R4, R5, R6, R7, R8, R9, R10: 10k; ESP32_WROVER_EAGLE-LTSPICE_R0402
R1_BAT: 200; ESP32_WROVER_EAGLE-LTSPICE_R0402
R1_PWRUSB: 100k; ESP32_WROVER_EAGLE-LTSPICE_R0402
R2: 2.2; ESP32_WROVER_EAGLE-LTSPICE_R0402
R2-USB, R2-USB1: 5k1; ESP32_WROVER_EAGLE-LTSPICE_R0402
R2_BAT: 2k; ESP32_WROVER_EAGLE-LTSPICE_R0402
R3: 0.47; ESP32_WROVER_EAGLE-LTSPICE_R0402
RESET_BUTTON: BUTTON_CUSYOMV1; MYBUTTON
R_BOOT: 10k; ESP32_WROVER_EAGLE-LTSPICE_R0402
R_CAPACITOR: 15; ESP32_WROVER_EAGLE-LTSPICE_R0402
R_CHANGE: 10k; ESP32_WROVER_EAGLE-LTSPICE_R0402
R_CL1: 10k; ESP32_WROVER_EAGLE-LTSPICE_R0402
R_RESET: 10k; ESP32_WROVER_EAGLE-LTSPICE_R0402
SENSOR2: ESP32_WROVER_BME680_BME680; ESP32_WROVER_BME680_PSON80P300X300X100-8N
SJ1: SJ
TP1, TP2, TP3, TP4, TP5, TP6, TP7, TP8, TP9, TP10, TP11, TP12, TP13, TP14, TP15, TP16, TP17: TPTP20R; TP20R
U1: W25Q512JVEIQ; SON127P600X800X80-9N
U2: ESP32-C6-WROOM-1-N8; XCVR_ESP32-C6-WROOM-1-N8
U3: DS3231SN#; SOIC127P1032X265-16N
U4: MAX17048G+T10; SON50P200X200X80-9N

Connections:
3V3: C1_BAT2.1, C3.+, C9.1, D7.2 (ANODE), IC1.2 (VDD), IC4.5 (VOUT), J3.2, J4.P4 (VDD), Q2.3 (D), R1.2, R1-PINH1.2, R2-PINH1.2, R5.2, R6.2, R7.2, R8.2, R9.2, R10.2, R_BOOT.2, R_CHANGE.2, R_CL1.2, R_RESET.2, TP16.TP, U1.3 (!WP!(IO2)), U1.7 (!HOLD!/!RESET!(IO3)), U1.8 (VCC), U2.2 (3V3), U3.2 (VCC)
32KHZ: R2-PINH1.1, U2.9 (IO1), U3.1 (32KHZ)
D_N: D1.1 (I/O1_1), J2.A7, J2.B7
D_P: D1.3 (I/O2_1), J2.A6, J2.B6
EPD_3V3: C7.1, EPD_C5.2, J1.15, J1.16, L1.2, Q2.2 (S), TP17.TP
EPD_3V3_C: Q2.1 (G), R_CL1.1, TP13.TP, U2.18 (IO20)
EPD_BUSY: J1.9, TP9.TP, U2.26 (IO3)
EPD_CS: D6.2, J1.12, R9.1, TP10.TP, U2.11 (IO10)
EPD_DC: J1.11, TP11.TP, U2.5 (IO5)
EPD_RST: J1.10, TP12.TP, U2.21 (IO23)
FLASH_CS: D9.2, R5.1, U1.1 (!CS), U2.12 (IO11)
GDR: J1.2, Q3.1 (G), R4.2
GND: BOOT_BUTTON.1, BOOT_BUTTON.2, C1.2, C1_BAT.2, C1_BAT1.2, C1_BAT2.2, C2.2, C2_BAT.2, C3.-, C4_USB.2, C5.2, C5_USB.2, C6.2, C7.2, C8.2, C9.2, C10.2, C10_SUPERCAP.1, CHANGE_BUTTON.1, CHANGE_BUTTON.2, C_DELAY.2, D1.5 (VBUS), D3.1 (K), D6.1, D8.1, D9.1, D10.1, D11.1, D12.1, EPD_C1.1, EPD_C2.1, EPD_C5.1, EPD_C6.1, EPD_C7.1, EPD_C8.1, EPD_C9.1, EPD_C10.1, EPD_C11.1, EPD_C12.1, IC1.3 (GND), IC4.2 (VSS), J1.8, J1.17, J1.MP1, J1.MP2, J2.A1, J2.A12, J2.B1, J2.B12, J2.MP1, J2.MP2, J2.MP3, J2.MP4, J3.1, J4.G1 (GND_1), J4.G2 (GND_2), J4.G3 (GND_3), J4.G4 (GND_4), J4.P6 (VSS), MCP73831.2 (VSS), R1_PWRUSB.1, R2.1, R2-USB.2, R2-USB1.1, R2_BAT.1, R4.1, RESET_BUTTON.1, RESET_BUTTON.2, SENSOR2.1 (GND), SENSOR2.5 (SDO), SENSOR2.7 (GND), SJ1.1, TP4.TP, TP5.TP, U1.4 (GND), U1.9 (EXP), U2.1 (GND), U2.28 (GND), U2.29_1 (GND), U2.29_2 (GND), U2.29_3 (GND), U2.29_4 (GND), U2.29_5 (GND), U2.29_6 (GND), U2.29_7 (GND), U2.29_8 (GND), U2.29_9 (GND), U3.13 (GND), U4.1 (CTG), U4.4 (GND), U4.6 (QSTRT), U4.9 (EP)
GPIO8: R1.1, U2.10 (IO8)
I2C_PW: C1.1, C2.1, R1_PINH.2, R2-PINH.2, SENSOR2.2 (CSB), SENSOR2.6 (VDDIO), SENSOR2.8 (VDD), U2.17 (IO19)
INT_RTC: R1-PINH1.1, TP15.TP, U2.8 (IO0), U3.3 (SQW/!INT)
IO/BOOT: BOOT_BUTTON.3, BOOT_BUTTON.4, C6.1, R_BOOT.1, U2.15 (IO9)
IO/CHANGE: C10.1, CHANGE_BUTTON.3, CHANGE_BUTTON.4, R_CHANGE.1, U2.23 (IO15)
MISO: D12.2, J4.P7 (DAT0), R8.1, TP6.TP, U1.2 (DO(IO1)), U2.27 (IO2)
MOSI: D11.2, J1.14, J4.P3 (CMD), R7.1, TP7.TP, U1.5 (DI(IO0)), U2.7 (IO7)
unnamed: J2.A5, R2-USB1.2
unnamed: C1_BAT1.1, D2.1 (CATHODE), IC4.1 (VIN), IC4.3 (CE), Q1.2 (S)
unnamed: C_DELAY.1, IC1.5 (CT)
unnamed: C4.1, D3.2 (A), D4.1 (K)
unnamed: MCP73831.1 (STAT), R1_BAT.2
unnamed: CHG_LED.C, R1_BAT.1
unnamed: MCP73831.5 (PROG), R2_BAT.2
unnamed: J2.B5, R2-USB.1
unnamed: EPD_C1.2, J1.4
unnamed: EPD_C2.2, J1.5
unnamed: D7.1 (CATHODE), R_CAPACITOR.2
unnamed: EPD_C6.2, J1.18
unnamed: EPD_C7.2, J1.19
unnamed: EPD_C8.2, J1.20
unnamed: EPD_C10.2, J1.22
unnamed: EPD_C12.2, J1.24
PREVGH: D5.1 (K), EPD_C9.2, J1.21
PREVGL: D4.2 (A), EPD_C11.2, J1.23
RESE: J1.3, Q3.2 (S), R3.2
RESE': R2.2, R3.1, SJ1.2
RESET: C5.1, IC1.1 (VOUT), RESET_BUTTON.3, RESET_BUTTON.4, R_RESET.1, U2.3 (EN)
RTC_RST: U2.16 (IO18), U3.4 (!RST)
RX: TP2.TP, U2.24 (RXD0/GPIO17)
SCK: D10.2, J1.13, J4.P5 (CLK), R6.1, TP8.TP, U1.6 (CLK), U2.6 (IO6)
SCL: J3.4, R2-PINH.1, SENSOR2.4 (SCK), U2.20 (IO22), U3.16 (SCL), U4.7 (SCL)
SDA: J3.3, R1_PINH.1, SENSOR2.3 (SDI), U2.19 (IO21), U3.15 (SDA), U4.8 (SDA)
SRC: C4.2, D5.2 (A), L1.1, Q3.3 (D)
SS_SD: D8.2, J4.P2 (CD/DAT3), R10.1, U2.4 (IO4)
TX: TP1.TP, U2.25 (TXD0/GPIO16)
USB_D+_N: D1.6 (I/O1_2), U2.13 (IO12)
USB_D+_P: D1.4 (I/O2_2), U2.14 (IO13)
VBAT: C2_BAT.1, MCP73831.3 (VBAT), Q1.3 (D), TP3.TP, U4.2 (CELL), U4.3 (VDD)
VBUS: C1_BAT.1, C4_USB.1, C5_USB.1, CHG_LED.A, D1.2 (GND), D2.2 (ANODE), MCP73831.4 (VIN), PFMF.050.1.2, Q1.1 (G), R1_PWRUSB.2, TP14.TP
VRTC: C8.1, C10_SUPERCAP.2, R_CAPACITOR.1, U3.14 (VBAT)
VUSB: J2.A4, J2.A9, J2.B4, J2.B9, PFMF.050.1.1

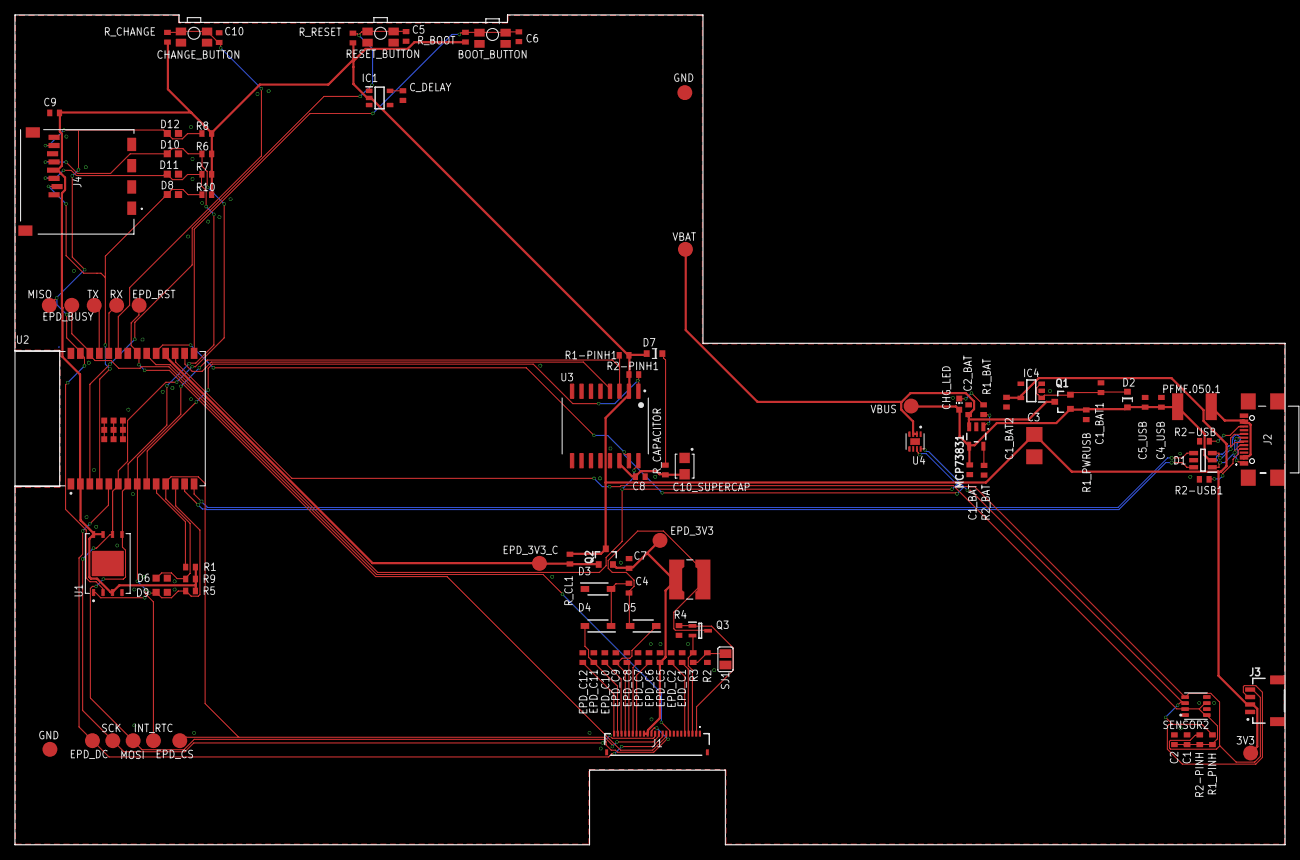
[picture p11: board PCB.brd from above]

Board: 2 copper layers, 170.2 x 111.2 mm, 103 parts (0 on the bottom side), 55 nets.

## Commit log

2025-04-06 Import project
    [Bill_of_Materials.csv, PCB.brd, PnP.csv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]
2025-04-16 Updated sch brd and 3d files.
    [OpenBook Enclosure.f3z, OpenBook_3D_Model.f3z, PCB.brd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]

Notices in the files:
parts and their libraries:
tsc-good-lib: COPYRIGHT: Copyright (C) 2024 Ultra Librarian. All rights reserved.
